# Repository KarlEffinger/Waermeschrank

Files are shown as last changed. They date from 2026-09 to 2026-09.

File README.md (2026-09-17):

# Wärmeschrank
Ein ESP32 Projekt zur Ansteuerung einer Heizung (bei mir getestet mit einer Heizmatte wie auch mit einem Heißluftgebläse).
Ich nutze diesen Wärmeschrank zum Verflüssigen meines Honigs, damit ich ihn dann mit meinem HaniMandl abfüllen kann ;-)
Per Drehgeber wird sowohl eine Solltemperatur als auch eine Ziel-Laufzeit eingestellt.
Sobald die Zieltemperatur das erste Mal erreicht wurde, beginnt die Laufzeit. Wird die Ziellaufzeit erreicht, schaltet sich die Heizung dauerhaft ab.
(Dauerhaft, weil aktuell noch eine 2-Punkt-Regelung mit +/- 0.5°C Hysterese und Relaissteuerung implementiert sind. Plan wäre, ggf auf eine PID-Regelung umzustellen).

Auf dem angeschlossenen LCD werden die Soll- und Ist-Temperatur, die Ziel-Laufzeit, die bisherige Laufzeit (auf Zieltemperatur) und die Restlaufzeit angezeigt, verbunden mit dem aktuellen Relaisstatus. Darunter gibt es eine Statuszeile mit Informationen zur WLAN- und MQTT-Verbindung, denn der ESP sendet alle 2 Minuten per MQTT seinen aktuellen Status und kann über eingehende MQTT-Nachrichten auch gesteuert werden.
waermeschrank gehaeuse

Die Einrichtung der WLAN- und MQTT-Verbindung erfolgt über einen Accesspoint, den der ESP aufspannt, wenn der Taster des Drehgebers länger als 3 Sekunden gedrückt wird.

Der Wärmeschrank meldet sich bei Home Assistant per MQTT Discovery selbst an: sobald er sich mit dem MQTT-Broker verbindet, legt er automatisch ein Gerät mit den Entities Relais, Solltemperatur, Ist-Temperatur, Solllaufzeit und Restlaufzeit an (inkl. Availability, d.h. HA zeigt an, ob das Gerät online ist).

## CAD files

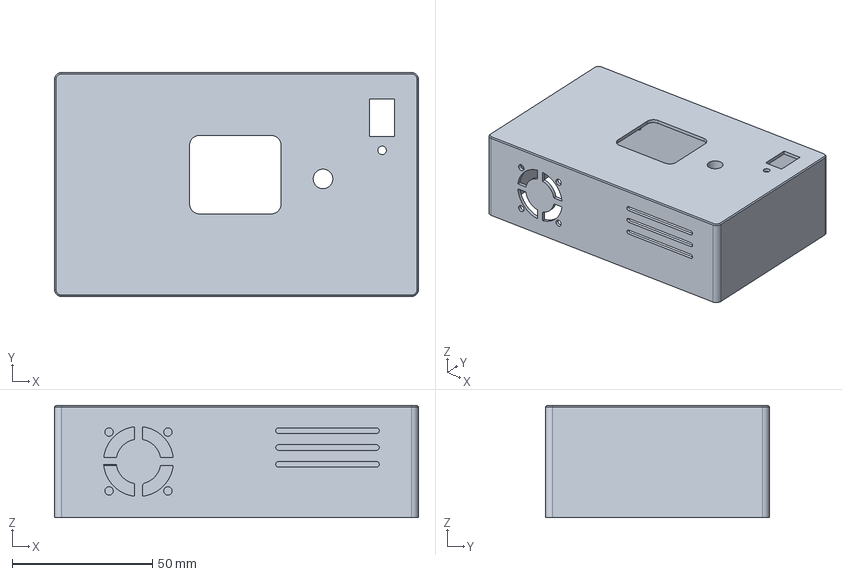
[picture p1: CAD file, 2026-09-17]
Wärmeschrank Elektronik.FCStd
130.0 x 80.0 x 40.0 mm

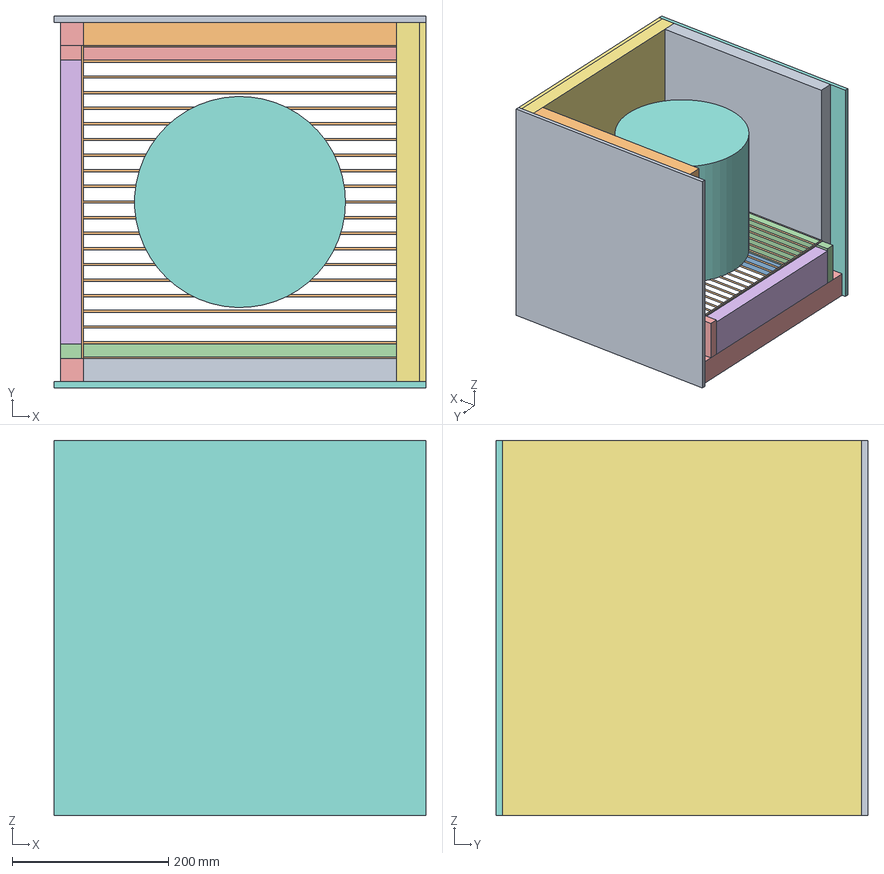
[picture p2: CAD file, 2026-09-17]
Wärmeschrank Gehäuse.FCStd
476.0 x 476.0 x 480.0 mm
Styro Seite vorne
Styro Seite hinten
Rahmen vorne
Rahmen hinten
Rahmen links
Rahmen rechts
Wand rechts
Wand vorne
Wand hinten
Gitterboden
Heizelement
Gitterbodenstütze vorne
Gitterbodenstütze hinten
Styro Seite links (fest)
Styro Seite rechts
Eimer

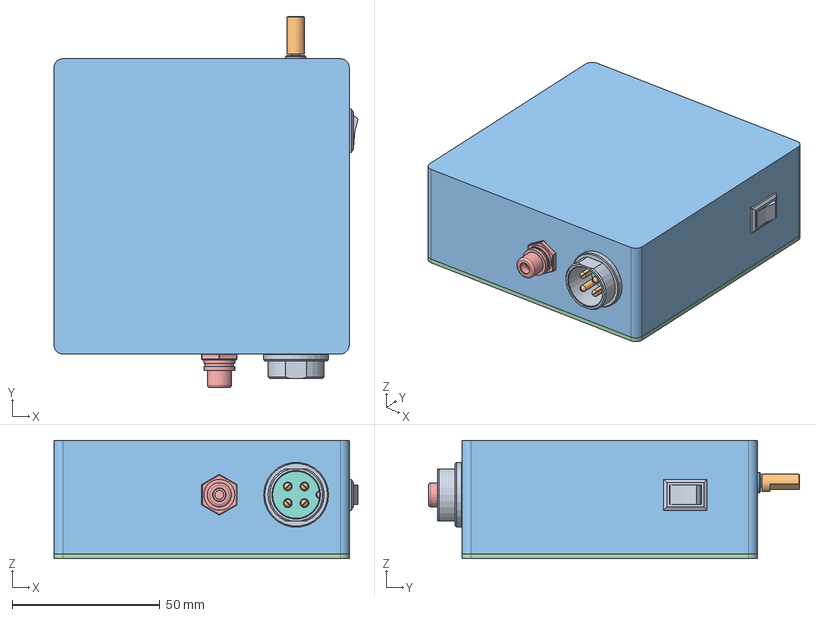
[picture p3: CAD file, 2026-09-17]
Wärmeschrank Elektronik schmal.FCStd
103.0 x 125.7 x 40.0 mm
PCB
Display
Pin
Pin001
Pin002
Pin003
Pin004
Pin005
Pin006
Pin007
R-0603
C-0603
U-0603
R-0604
R-0605
C-0604
Schalter10x15 (9,0x13,3)001
pcb
mtg flange
body_encoder
5 pin header
90d pin_header
90d pin_header001
90d pin_header002
90d pin_header003
90d pin_header004
decal_encoder
shaft_encoder
Tornillo M3X15 v8
Tornillo M3X15 v009
Tornillo M3X15 v010
Pin_interno v17
Pin_interno v018
Pin_interno v019
Punto se soldadura v8
Punto se soldadura v009
Punto se soldadura v010
Punto se soldadura v011
Punto se soldadura v012
Punto se soldadura v013
Punto se soldadura v014
Punto se soldadura v015
Punto se soldadura v016
Punto se soldadura v017
Punto se soldadura v018
Relevador 5VDC v18
Diodo M7 v13
LED VERDE SMD v7
RESISTENCIA 151 v3
Transistor v18
Header_Body
Header_Body001
Header_Body002
Pin008
Pin009
Pin010
ESP32
Cinch_Body
Mutter
Lötfahne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

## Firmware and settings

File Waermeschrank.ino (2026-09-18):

 /*============================================================================
 * Wärmeschrank-Steuerung mit LVGL GUI und MQTT
 * ============================================================================
 * 
 * Hardware:
 * - ESP32 DevKit
 * - TFT-Display 1.69" mit ST7789 v2 Treiber (SPI)
 * - Rotary Encoder mit Taster (HW-040)
 * - Temperatursensor DS18B20
 * - Relais für Heizungssteuerung
 * 
 * Funktionen:
 * - Temperaturgeregelte Heizungssteuerung mit Hysterese
 * - Zeitbasierte Laufzeitüberwachung
 * - MQTT-Integration für Remote-Steuerung und Monitoring
 * - WiFi-Konfiguration über Web-Interface
 * - Grafische Benutzeroberfläche mit LVGL
 * 
 * Bedienung:
 * - Kurzer Tastendruck: Wechsel zwischen Temperatur- und Zeiteinstellung
 * - Langer Tastendruck (>3s): Konfigurationsmodus starten
 * - Encoder drehen: Wert ändern (je nach Modus)
 * 
 * MQTT Topics:
 * - [base]/temp_ist        : Aktuelle Temperatur (wird gesendet, retained)
 * - [base]/temp_soll       : Solltemperatur (wird gesendet und empfangen, retained)
 * - [base]/relay           : Relaisstatus (wird gesendet, retained)
 * - [base]/sollLaufzeit    : Solllaufzeit in ms (wird gesendet, retained)
 * - [base]/restLaufzeit    : Restlaufzeit in ms (wird gesendet, retained)
 * - [base]/set_temp_soll   : Solltemperatur setzen (Empfang)
 * - [base]/set_laufzeit    : Laufzeit setzen in Minuten (Empfang)
 * - [base]/status          : Availability "online"/"offline" (retained, Last Will and Testament)
 *
 * Home Assistant MQTT Discovery:
 * - Beim Verbinden wird fuer jede Entity eine retained Config-Nachricht nach
 *   homeassistant/<component>/<geraete-id>/<object_id>/config veroeffentlicht.
 * - <geraete-id> ist eine aus der Chip-ID abgeleitete, stabile Kennung (siehe
 *   haDeviceId in setup()) - unabhaengig vom hier konfigurierbaren [base]-Topic.
 *   Aendert sich [base] (z.B. ueber die Web-Konfiguration), bleiben die
 *   HA-Entities dadurch erhalten; nur die referenzierten Topics im
 *   Config-Payload werden beim naechsten Verbindungsaufbau aktualisiert.
 *
 * Autor: Karl Effinger
 *
 * Change log
 *
 * v1.3.1 - 2026-09-18 - Display Self-Heal gegen sporadisches Bildrauschen:
 *                       zwei Full-Redraws kurz nach dem Boot (3s/8s) plus
 *                       periodischer Full-Redraw alle 3 Minuten waehrend
 *                       der Laufzeit (deckt auch spaeter auftretende
 *                       SPI-Korruption einzelner Partial-Updates ab, nicht
 *                       nur den initialen Boot-Flush), SPI_FREQUENCY der
 *                       TFT_eSPI-Lib von 27 auf 20 MHz gesenkt (mehr
 *                       Stoerabstand auf der Breadboard-Verkabelung)
 * v1.3.0 - 2026-09-17 - Taster-Debounce ueberarbeitet (ISR-Timestamp statt
 *                       Race-anfaelligem digitalRead), MQTT-Connect-Timeout
 *                       (2s), non-blocking WiFi-Reconnect, lv_refr_now/
 *                       lv_tick_inc/millis-Overflow-Fixes, WiFi.setSleep(false),
 *                       MQTT Availability (LWT) + retained Publishes,
 *                       Home Assistant MQTT Discovery (5 Entities, stabile
 *                       Geraete-ID aus Chip-ID)
 * v1.2.0 - 2025-11-13 - Zeiteinstellung umgestellt, GUI überarbeitet
 * v1.1.0 - 2025-11-11 - Umstellung auf AiEsp32RotaryEncoder Bibliothek
 * v1.0.0 - 2025-11-06 - Finale Version mit Kommentaren
 * 
 * Bekannte Einschränkungen:
 * - NVS Flash hat begrenzte Schreibzyklen (~100.000)
 * - MQTT wird nach 10 fehlgeschlagenen Versuchen bis zum Neustart deaktiviert
 * 
 * Ideen für Verbesserungen:
 * - Mehrere Temperaturzonen
 * - PID-Regelung statt einfacher Hysterese
 * 
 * Kontakt: kaeff@gmx.de
 */

// ============================================================================
// Debugging, für Produktivsystem erste Zeile (#define DEBUG) auskommentieren
// ============================================================================
  //#define DEBUG
  #ifdef DEBUG
    #define DBEGIN() do { Serial.begin(115200); delay(100); } while(0)
    #define DPRINT(...) Serial.print(__VA_ARGS__)
    #define DPRINTLN(...) Serial.println(__VA_ARGS__)
    #define DPRINTF(...) Serial.printf(__VA_ARGS__)
    #define DFLUSH() Serial.flush()
    #include <esp_system.h>
  #else
    #define DBEGIN()
    #define DPRINT(...)
    #define DPRINTLN(...)
    #define DPRINTF(...)
    #define DFLUSH()
  #endif

// ============================================================================
// Bibliotheken
// ============================================================================

  #include <lvgl.h>                    // v8.3.11 Grafik-Bibliothek für GUI [WICHTIG: läuft nicht mit v9.x!] https://github.com/lvgl
  #include <TFT_eSPI.h>                // v2.5.43 TFT-Display-Treiber. https://github.com/Bodmer/TFT_eSPI
  #include <OneWire.h>                 // v2.3.8  1-Wire Protokoll für DS18B20. https://github.com/PaulStoffregen/OneWire
  #include <DallasTemperature.h>       // v4.0.5  DS18B20 Temperatursensor. https://github.com/milesburton/Arduino-Temperature-Control-Library
  #include <AiEsp32RotaryEncoder.h>    // v1.7    Drehencoder mit Taster https://github.com/igorantolic/ai-esp32-rotary-encoder
  #include <WiFi.h>                    // v3.3.2  WiFi-Funktionalität. Integriert in ESP32-Library
  #include <WebServer.h>               // v3.3.2  Webserver für Konfiguration. Integriert in ESP32-Library
  #include <Preferences.h>             // v3.3.2  Persistente Speicherung (NVS). Integriert in ESP32-Library
  #include <PubSubClient.h>            // v2.8    MQTT-Client. https://github.com/knolleary/pubsubclient/releases/tag/v2.8


// ============================================================================
// Hardware-Konfiguration
// ============================================================================
  #define ONE_WIRE_BUS 26              // GPIO für DS18B20 Temperatursensor
  #define RELAY_PIN 27                 // GPIO für Relais-Ansteuerung
  #define ROTARY_ENCODER_A_PIN 34      // CLK Pin
  #define ROTARY_ENCODER_B_PIN 35      // DT Pin
  #define ROTARY_ENCODER_BUTTON_PIN 32 // SW Pin
  #define ROTARY_ENCODER_VCC_PIN 33    // VCC Pin (optional)
  
// ============================================================================
// Display-Konfiguration (TFT_eSPI)
// ============================================================================
// HINWEIS: Pin-Konfiguration muss in User_Setup.h der TFT_eSPI Bibliothek erfolgen!
// Dort ist aktuell hinterlegt: CS: 21 / RST: 18 / DC: 19 / SCLK: 17 / MOSI bzw. SDA: 5
  TFT_eSPI tft = TFT_eSPI();

// ============================================================================
// LVGL Display-Konstanten und Puffer
// ============================================================================
  #define LVGL_DISPLAY_WIDTH 280       // Display-Breite in Pixel
  #define LVGL_DISPLAY_HEIGHT 240      // Display-Höhe in Pixel
  #define LVGL_DISPLAY_BUF_ROWS 40     // Anzahl Zeilen im Puffer
  #define LVGL_DISPLAY_BUF_SIZE (LVGL_DISPLAY_WIDTH * LVGL_DISPLAY_BUF_ROWS)

  static lv_disp_draw_buf_t draw_buf;  // LVGL Zeichenpuffer-Struktur
  static lv_color_t buf1[LVGL_DISPLAY_BUF_SIZE]; // Farbpuffer für Display
  static lv_disp_drv_t disp_drv;       // LVGL Display-Treiber

// ============================================================================
// GUI-Objekte (LVGL Labels)
// ============================================================================
  lv_obj_t *label_soll;                // Label: Soll-Temperatur
  lv_obj_t *label_ist;                 // Label: Ist-Temperatur
  lv_obj_t *label_sollzeit;            // Label: Sollzeit (hh:mm)
  lv_obj_t *label_istzeit;             // Label: Verstrichene Zeit
  lv_obj_t *label_timer;               // Label: Verbleibende Zeit
  lv_obj_t *label_relay;               // Label: Relaisstatus
  lv_obj_t *label_status;              // Label: WiFi/MQTT Status
  lv_obj_t *blink_dot;                 // Kleiner blinkender Kreis (grün) im Sekundentakt

// -------------------- GUI: cache / flags für sofortige Updates --------------------
// Damit die unmittelbaren Updates nicht mit gecacheden internen Werten in update_gui
// kollidieren, speichern wir die zuletzt gezeigten Werte global.
static int gui_last_sollTemp = -32768;
static float gui_last_istTemp = -1000.0f;
static int gui_lastColorCode = -1;
static int gui_lastEncoderModeForSoll = -1;
static unsigned long gui_last_soll_minutes = ULONG_MAX;
static unsigned long gui_last_ist_minutes = ULONG_MAX;
static unsigned long gui_last_rest_minutes = ULONG_MAX;
static int gui_lastEncoderModeForTime = -1;
static bool gui_lastRelayOn = false;
static char gui_last_status[64] = "";

// ============================================================================
// DS18B20 Temperatursensor
// ============================================================================
  OneWire oneWire(ONE_WIRE_BUS);       // 1-Wire Bus initialisieren
  DallasTemperature sensors(&oneWire); // Temperatursensor-Bibliothek
  DeviceAddress sensorAddress;         // Adresse des ersten gefundenen Sensors

  // Temperatursensor - Timing und Status
  unsigned long lastRequest = 0;       // Zeitpunkt der letzten Messanforderung
  bool tempRequested = false;          // Flag: Messung wurde angefordert
  const unsigned long tempRequestInterval = 10*1000;  // Messintervall: 10 Sekunden
  const unsigned long tempConversionDelay = 250;      // Wartezeit für A/D-Wandlung des DS18B20: bei 10 Bit ca. 200ms

// ============================================================================
// Rotary Encoder (Drehgeber mit Taster)
// ============================================================================
  #define ROTARY_ENCODER_STEPS 2       // Schritte pro Detent
  AiEsp32RotaryEncoder rotaryEncoder = AiEsp32RotaryEncoder(
    ROTARY_ENCODER_A_PIN, 
    ROTARY_ENCODER_B_PIN, 
    ROTARY_ENCODER_BUTTON_PIN, 
    ROTARY_ENCODER_VCC_PIN,
    ROTARY_ENCODER_STEPS
  );

  int encoderMode = 0;                 // 0=Temperatur, 1=Laufzeit
  bool configModeRequested = false;    // Flag: Config-Modus angefordert, nach >3 Sekunden Tastendruck (siehe LONG_PRESS_TIME)

  // Button-Erfassung: die ISR haelt nur den zuletzt gesehenen Pegel + Zeitstempel fest
  // (kein digitalRead() im Loop noetig). Die eigentliche Entprellung (Pegel muss
  // DEBOUNCE_DELAY ms stabil sein) passiert in rotary_loop(). Dadurch gehen Flanken
  // nicht verloren, auch wenn loop() mal kurz blockiert (z.B. MQTT-Connect-Versuch).
  volatile bool isrButtonLevel = HIGH;
  volatile unsigned long isrLevelChangeTime = 0;
  const unsigned long DEBOUNCE_DELAY = 30;   // 30ms Entprellung (wie AiEsp32RotaryEncoder intern)

  // Button-Timing für langen Tastendruck
  unsigned long buttonPressStartTime = 0;
  bool buttonWasPressed = false;
  const unsigned long LONG_PRESS_TIME = 3000; // 3 Sekunden

// ============================================================================
// Systemzustände und Parameter
// ============================================================================
  float istTemp = 0.0;                 // Aktuelle Temperatur in °C
  int sollTemp = 40;                   // Solltemperatur in °C (Standard: 40°C)
  int lastSavedSollTemp;               // Zuletzt gespeicherte Solltemperatur

  unsigned long startTime = 0;         // Startzeitpunkt des Timers (0=inaktiv)
  unsigned long laufzeit = 0 * 60 * 60 * 1000; // Laufzeit in ms (Standard: 0h - sonst geht nach einem Stromausfall die Kiste wieder an!)
  const unsigned long LAUFZEIT_STEP_MS = 60*1000UL; // 1 Minute pro Encoder-Step
  bool LaufzeitEnde = false;           // Flag: Laufzeit abgelaufen

  // Auto-Save Konfiguration
  unsigned long lastConfigSave = 0;    // Zeitpunkt der letzten Config-Speicherung
  const unsigned long configSaveInterval = 5 * 60 * 1000; // Speicher-Intervall: 5 Minuten

// ============================================================================
// Relais-Steuerung
// ============================================================================
  const float hysterese = 0.5;         // Hysterese in °C (±0.5°C)
  bool relayOn = false;                // Aktueller Relaisstatus

// ============================================================================
// WiFi und MQTT Konfiguration
// ============================================================================
  WiFiClient espClient;                // WiFi-Client für MQTT
  PubSubClient mqttClient(espClient);  // MQTT-Client
  Preferences preferences;             // NVS (Non-Volatile Storage) für Einstellungen

  // WiFi-Zugangsdaten (werden aus NVS geladen)
  String wifi_ssid = "";
  String wifi_password = "";

  // WiFi Reconnect-Logik (non-blocking, im Gegensatz zu MQTT KEIN Abschalten nach
  // X Fehlversuchen - eine WLAN-Unterbrechung (z.B. Router-Neustart) soll das
  // Geraet nicht dauerhaft offline lassen).
    unsigned long lastWifiReconnectAttempt = 0;      // Zeitpunkt des letzten Versuchs
    const unsigned long wifiReconnectCooldown = 30 * 1000; // Pause zwischen Versuchen: 30 Sekunden

  // MQTT-Verbindungsdaten (werden aus NVS geladen)
  String mqtt_server = "";
  int mqtt_port = 1883;
  String mqtt_user = "";
  String mqtt_password = "";
  String mqtt_topic_base = "waermeschrank";  // Basis-Topic für alle MQTT-Nachrichten

  // Home Assistant Discovery: stabile Geraete-ID aus der Chip-ID (unabhaengig
  // von mqtt_topic_base). Wird einmalig in setup() befuellt.
  String haDeviceId = "";

  // MQTT Publish-Timing
    unsigned long lastMqttPublish = 0;   // Zeitpunkt des letzten MQTT-Publish
    const unsigned long mqttPublishInterval = 2 * 60 * 1000; // Publish-Intervall: 2 Minuten

  // MQTT Reconnect-Logik
    int mqttReconnectAttempts = 0;       // Anzahl fehlgeschlagener Verbindungsversuche
    const int maxMqttReconnectAttempts = 10; // Max. Versuche vor Deaktivierung
    unsigned long lastMqttReconnectAttempt = 0; // Zeitpunkt des letzten Versuchs
    const unsigned long mqttReconnectCooldown = 60 * 1000; // Pause zwischen Versuchen: 1 Minute
    bool mqttEnabled = true;             // Flag: MQTT aktiv (wird bei zu vielen Fehlern false)

  // MQTT Status-Anzeige
  bool mqttSending = false;            // Flag: MQTT-Daten werden gerade gesendet
  unsigned long mqttSendingStartTime = 0; // Startzeitpunkt der Sendeanzeige

// ============================================================================
// Webserver für Konfiguration
// ============================================================================
  WebServer server(80);                // Webserver auf Port 80
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
void loop() {
  // --------------------------------------------------------------------------
  // Config-Modus prüfen (>3s Tastendruck) und ggf. starten
  // --------------------------------------------------------------------------
  if (configModeRequested) {
    enterConfigMode();                // Config-Modus mit Web-Interface
    ESP.restart();                    // Nach Config-Änderungen Neustart
  }
  
  // --------------------------------------------------------------------------
  // LVGL Zeitbasis aktualisieren (tatsaechlich vergangene Zeit, nicht fix 5ms)
  // --------------------------------------------------------------------------
  static unsigned long lv_last_tick = 0;
  unsigned long now = millis();
  if (lv_last_tick == 0) lv_last_tick = now;
  unsigned long lv_elapsed = now - lv_last_tick; // unsigned-Subtraktion: overflow-sicher
  if (lv_elapsed >= 5) {
    lv_tick_inc(lv_elapsed);          // LVGL die wirklich vergangene Zeit mitteilen
    lv_last_tick = now;               // (nicht += 5, sonst summiert sich die Drift auf)
  }

  lv_task_handler();                  // LVGL Tasks verarbeiten
  delay(5);                           // Kurze Pause für Task-Scheduler

  // --------------------------------------------------------------------------
  // Display Self-Heal: SPI-Störungen (z.B. durch die Breadboard-Verkabelung)
  // können nicht nur den initialen Full-Redraw beim Boot korrumpieren,
  // sondern auch einzelne spätere Partial-Updates - beobachtet z.B. als
  // grün eingefärbte Flächen, die deutlich größer sind als das eigentlich
  // aktualisierte Element (blink_dot/Ist-Temperatur-Farbe sind grün). Das
  // deutet auf ein gekipptes Bit im SPI-Kommando für das Adressfenster
  // (setAddrWindow) hin, wodurch zu viele Pixel mit der falschen Farbe
  // beschrieben werden. Da LVGL nur geänderte Bereiche neu zeichnet, bleibt
  // so ein Fehler stehen, bis das betroffene Element zufällig erneut
  // aktualisiert wird. Um das zu heilen, wird der komplette Screen zweimal
  // kurz nach dem Start (3s/8s, deckt den Boot-Flush ab) und danach
  // periodisch (alle 3 Minuten, deckt spätere Laufzeit-Korruption ab) neu
  // invalidiert und komplett über SPI neu übertragen.
  // --------------------------------------------------------------------------
  static unsigned long nextSelfHeal = 3000;
  static uint8_t selfHealBootStage = 0;
  const unsigned long selfHealRuntimeInterval = 3UL * 60UL * 1000UL; // alle 3 Minuten
  if (now >= nextSelfHeal) {
    lv_obj_invalidate(lv_scr_act());
    if (selfHealBootStage == 0) {
      nextSelfHeal = 8000;
      selfHealBootStage = 1;
    } else {
      nextSelfHeal = now + selfHealRuntimeInterval;
    }
  }

  // --------------------------------------------------------------------------
  // DS18B20 Temperaturmessung (non-blocking)
  // --------------------------------------------------------------------------
  startTemperatureRequestIfNeeded(); // Neue Messung starten wenn fällig
  readTemperatureIfReady();          // Messergebnis abholen wenn fertig
  
  // --------------------------------------------------------------------------
  // Rotary Encoder auslesen
  // --------------------------------------------------------------------------
  rotary_loop();
  
  // HINWEIS: Kein separater millis()-Overflow-Schutz nötig - alle Laufzeit-
  // Vergleiche unten nutzen bereits das Muster "millis() - startTime >= laufzeit"
  // mit unsigned-Subtraktion, das ist beim Wrap nach ~49,7 Tagen automatisch
  // korrekt. Ein expliziter "millis() < startTime"-Check wuerde in genau diesem
  // Fenster faelschlich die bereits korrekt gezaehlte Laufzeit verwerfen.

  // --------------------------------------------------------------------------
  // Relais-Steuerung mit Hysterese und Laufzeitüberwachung
  // --------------------------------------------------------------------------
  // Prüfen ob Laufzeit abgelaufen ist
  if (!LaufzeitEnde && startTime > 0 && (millis() - startTime >= laufzeit)) {
    LaufzeitEnde = true;
    DPRINTLN("Laufzeit abgelaufen – Relais wird deaktiviert.");
  }
  // Prüfen ob Laufzeit wieder neu gestartet wurde (z.B. durch Änderung)
  else if (LaufzeitEnde && startTime > 0 && (millis() - startTime <= laufzeit)) {
    DPRINTLN("Laufzeit wieder gestartet und Relais reaktiviert.");
    LaufzeitEnde = false;
  }
  


// Laufzeit-Check: Ist überhaupt eine Laufzeit gesetzt?
  bool laufzeitAktiv = (laufzeit > 0);
  
  // Bestimmen ob Laufzeit das Heizen erlaubt
  bool laufzeitErlaubtHeizen = false;
  if (!laufzeitAktiv) {
    // Keine Laufzeit gesetzt (0 Minuten) -> Heizen nicht erlaubt
    laufzeitErlaubtHeizen = false;
  } else if (startTime == 0) {
    // Timer noch nicht gestartet, aber Laufzeit gesetzt -> Heizen erlaubt (Aufheizphase)
    laufzeitErlaubtHeizen = true;
  } else {
    // Timer läuft -> nur erlaubt wenn noch nicht abgelaufen
    laufzeitErlaubtHeizen = !LaufzeitEnde;
  }
  
  // Relais einschalten wenn: Temperatur zu niedrig UND Laufzeit erlaubt Heizen
  if (!relayOn && laufzeitErlaubtHeizen && istTemp != DEVICE_DISCONNECTED_C && istTemp <= (sollTemp - hysterese)) {
    relayOn = true;
    digitalWrite(RELAY_PIN, HIGH);
  }
  // Relais ausschalten wenn: Temperatur zu hoch (Solltemperatur erreicht)
  else if (relayOn && istTemp >= (sollTemp + hysterese)) {
    relayOn = false;
    digitalWrite(RELAY_PIN, LOW);
    // Timer starten wenn Solltemperatur das erste Mal erreicht wurde
    if (laufzeitAktiv && startTime == 0) {
      startTime = millis();
      DPRINTLN("Timer gestartet - Solltemperatur erreicht!");
    }
  }
  // Relais ausschalten wenn: Laufzeit abgelaufen oder keine Laufzeit gesetzt
  else if (relayOn && (!laufzeitErlaubtHeizen)) {
    relayOn = false;
    digitalWrite(RELAY_PIN, LOW);
  }

  // Relais ausschalten, wenn der Temp-Sensor keine Daten liefert
  if (relayOn && istTemp == DEVICE_DISCONNECTED_C) {
    relayOn = false;
    digitalWrite(RELAY_PIN, LOW);
    DPRINTLN("Relais wegen Sensor-Fehler ausgeschaltet!");
  }
  
  // --------------------------------------------------------------------------
  // WiFi-Verbindung überwachen und bei Abbruch non-blocking neu verbinden
  // --------------------------------------------------------------------------
  // Anders als bei MQTT: keine dauerhafte Abschaltung nach X Versuchen - eine
  // WLAN-Unterbrechung (Router-Neustart, kurze Stoerung) soll das Geraet nicht
  // bis zum naechsten Stromzyklus offline lassen. WiFi.reconnect() blockiert
  // nicht (im Gegensatz zu connectWiFi(), das haben wir hier bewusst nicht
  // wiederverwendet).
  if (wifi_ssid.length() > 0 && WiFi.status() != WL_CONNECTED) {
    if (millis() - lastWifiReconnectAttempt >= wifiReconnectCooldown) {
      DPRINTLN("WiFi nicht verbunden - Reconnect-Versuch...");
      WiFi.reconnect();
      lastWifiReconnectAttempt = millis();
    }
  }
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

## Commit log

2025-11-26 Update README.md
    added housing image
2026-09-17 MQTT-Stabilitaet, Availability/Retain und HA-Discovery hinzugefuegt
    - Taster-Debounce ueberarbeitet (ISR-Timestamp statt Race-anfaelligem digitalRead)
    - MQTT-Connect-Timeout (2s), non-blocking WiFi-Reconnect
    - lv_refr_now/lv_tick_inc/millis-Overflow-Fixes, WiFi.setSleep(false)
    - MQTT Availability (LWT) + retained Publishes
    - Home Assistant MQTT Discovery: 5 Entities, stabile Geraete-ID aus Chip-ID
    [Wärmeschrank Elektronik schmal.FCStd, Wärmeschrank Elektronik.FCStd, Wärmeschrank Gehäuse.FCStd]
2026-09-18 Display Self-Heal gegen sporadisches Bildrauschen (v1.3.1)
    SPI-Stoerungen auf der Breadboard-Verkabelung koennen sowohl den
    initialen Full-Redraw beim Boot als auch spaetere Partial-Updates
    korrumpieren (beobachtet u.a. als grosse gruen eingefaerbte Flaechen).
    Da LVGL nur geaenderte Bereiche neu zeichnet, blieb so ein Fehler
    dauerhaft stehen. Fix: kompletter Screen-Redraw 3s/8s nach dem Boot
    und danach periodisch alle 3 Minuten.
    [Waermeschrank.ino]
